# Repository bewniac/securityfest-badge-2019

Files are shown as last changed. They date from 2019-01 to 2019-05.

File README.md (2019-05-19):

# Security fest 2019 - n00Badge
Here you go, all the code and files that exist as a part of the official Security fest 2019 badge we call "n00Badge". First of all, you should know that I'm a complete n00b (hence the name) and this is my first ever project designing a PCB from scratch. I've learned a lot and it was a lot of fun with more headaches than I could count. I recommend everyone wanting to get into electronics to do what I did, get an idea what you want to do and then, like Nike say, Just do it!

The schematics and PCB design are all made in [KiCAD](http://kicad-pcb.org/) which is an Open Source Electrionics design suite. There's a lot of PCB footprints and schematic symbols for KiCAD and it's easy to make your own. There's other suites available but I use KiCAD because it was my first result on Google. 

I wanted to do something cool for Security fest 2019 and I wanted to do it myself from scratch. So I got my hands on my first ESP8266 board, the ESP-12F. It's a WiFi IoT thingy and can both work as an Access Point and a WiFi client and you can get it for 3 USD, or about 50 SEK if you buy it in Sweden. Now I have a WiFi capable microcontroller. But I wanted more. So I bought a Nokia 5110 LCD screen which costs about the same as the ESP-12F. This became my head requirements for the project:

  * Nokia 5110 LCD
  * ESP8266
  * Powered by micro USB

Simple enough. I built a prototype that could be powered by 5V micro USB. Although the components require 3.3V, but with a voltage regulator (LD1117V33) this wasn't an issue. The result was this:

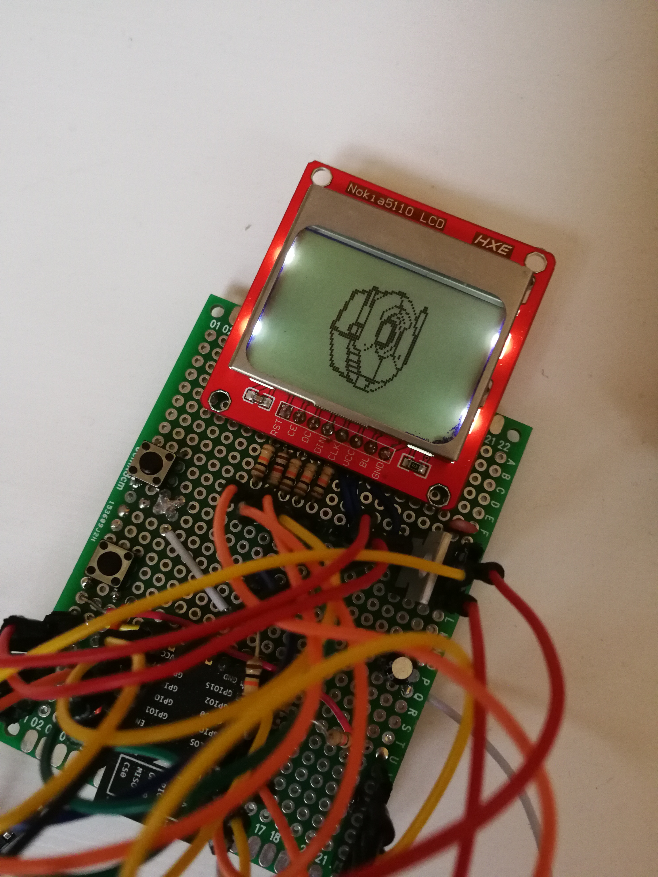
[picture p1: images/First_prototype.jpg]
First Prototype


Not so pretty, I know. But it worked. But then I wanted to create my own PCB prototype, with as much hand-solderable components as possible as I've never done SMD soldering before. I created my first schematic and PCB design in KiCAD. 

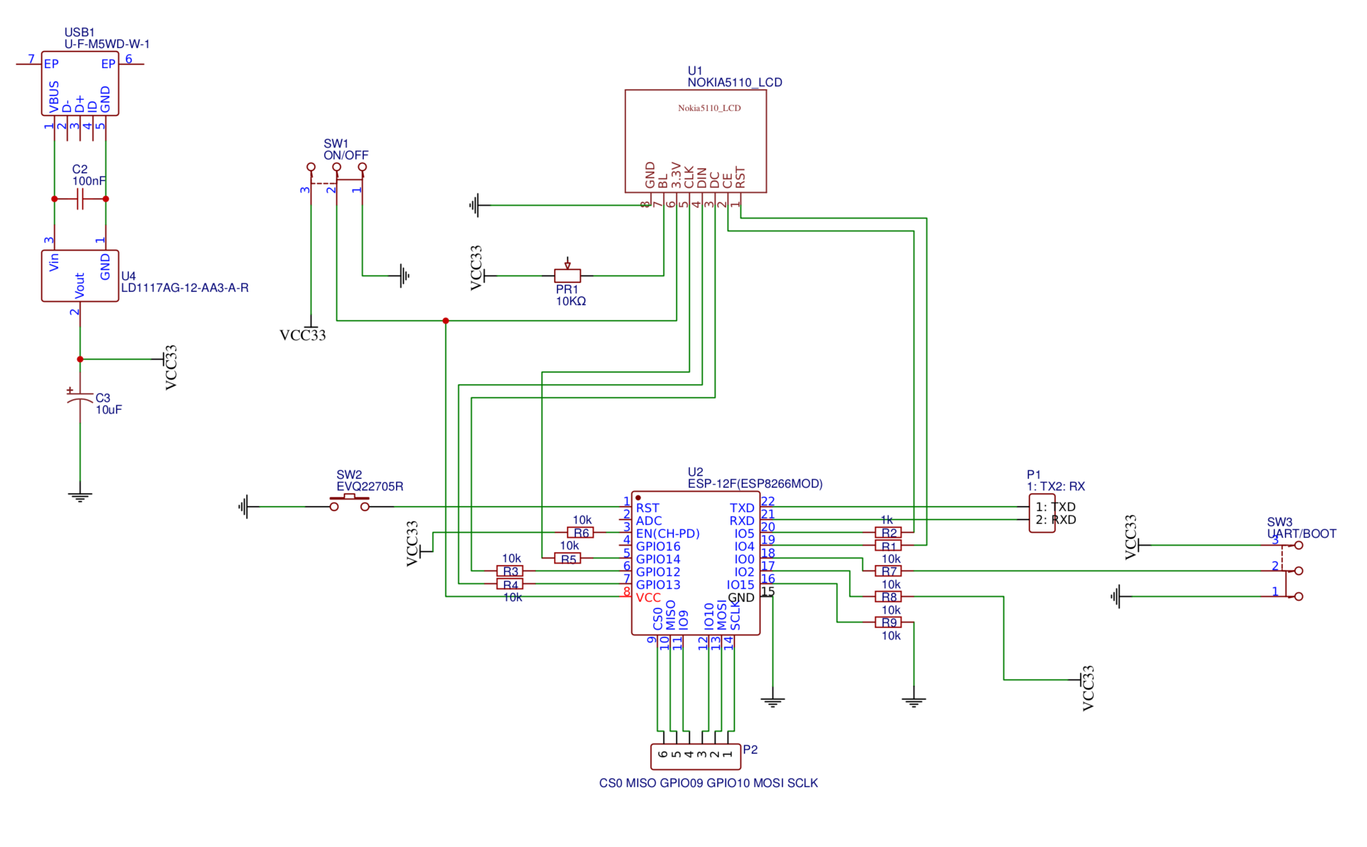
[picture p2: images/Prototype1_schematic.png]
Schematic prototype

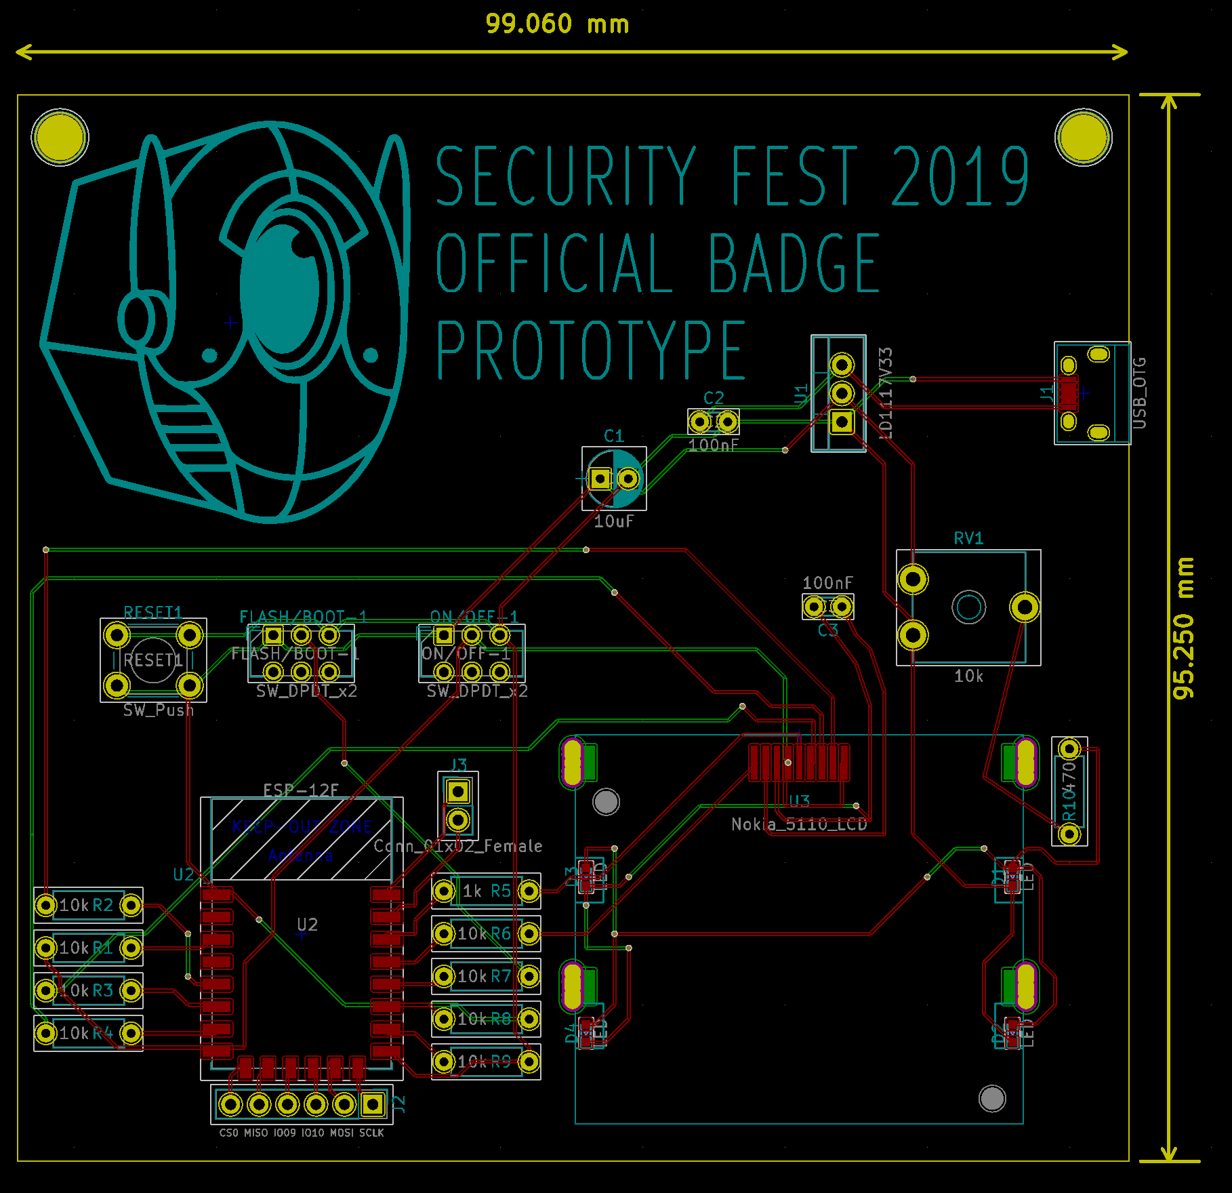
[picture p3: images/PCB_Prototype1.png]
PCB Prototype


Still not pretty, but much better than my hand-made prototype and very fun to do! I ordered 10 PCBs from https://jlcpcb.com/ and the components I was missing from https://lcsc.com/ and waited. When it arrived I was extatic! My first PCB! I soldered all the components as soon as I got it (although I had to fix some errors with the backlight LEDs at first, I forget a GND route to the backlight LEDs). 

PCB

When I did some programming trying to come up with some fun stuff to add I found I was missing something, buttons for user interaction. So I had to modify the badge a bit. I used the ADC (Analog to Digital Converter) pin to add two buttons and controll them with one pin. This can be done by adding resistors of different value to the GND leg of each button. The analog voltage is converted by the pin to a digital number. The resistors will reduce the voltage to different values on each button, hence the digital number will be differ between the buttons and I can make descisions in the code based on those values. Next I had a brilliant idea, it has to be battery powered! A Li-Po battery should do the trick. But we also like to charge the Li-Po battery. So I modified my prototype by hand, added buttons, a Li-Po battery and a Li-Po charger circuit (from Adafruit, which is open hardware and the schematics are avaiable on their website). The result was this:

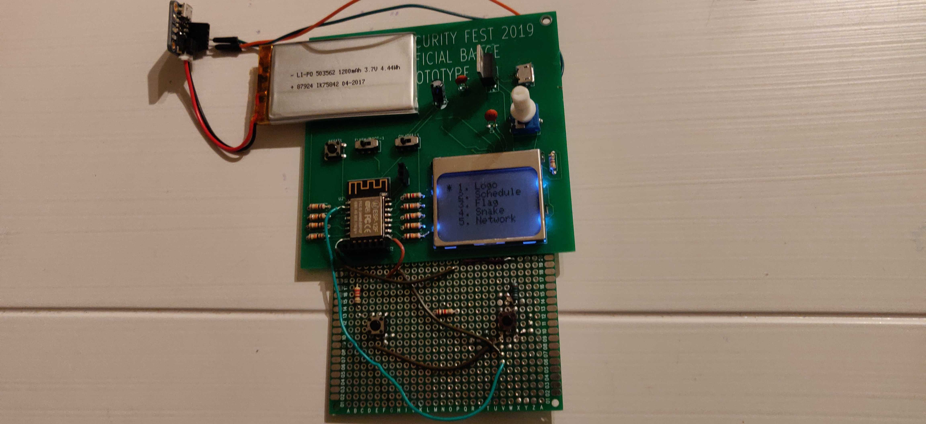
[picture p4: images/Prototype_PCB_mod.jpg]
PCB_MOD


So now I got a prototype I feel pretty good about to work on. It runs on battery and the battery can be charged, AWESOME! Now I want to make the final design. A square badge feels so boring and we've got a cool logo to work with. So I started to create a schematic including the charging curcuit (based on the Adafruit schematic) and the buttons. And I also made some changes I replaced the ESP-12F module for the new ESP-12S module. Same form-factor, removed unnecessary pins and little faster CPU frequency. I had to edit the ESP-12F module PCB footprint myself to get a footprint for the new component. 

The final schematic:

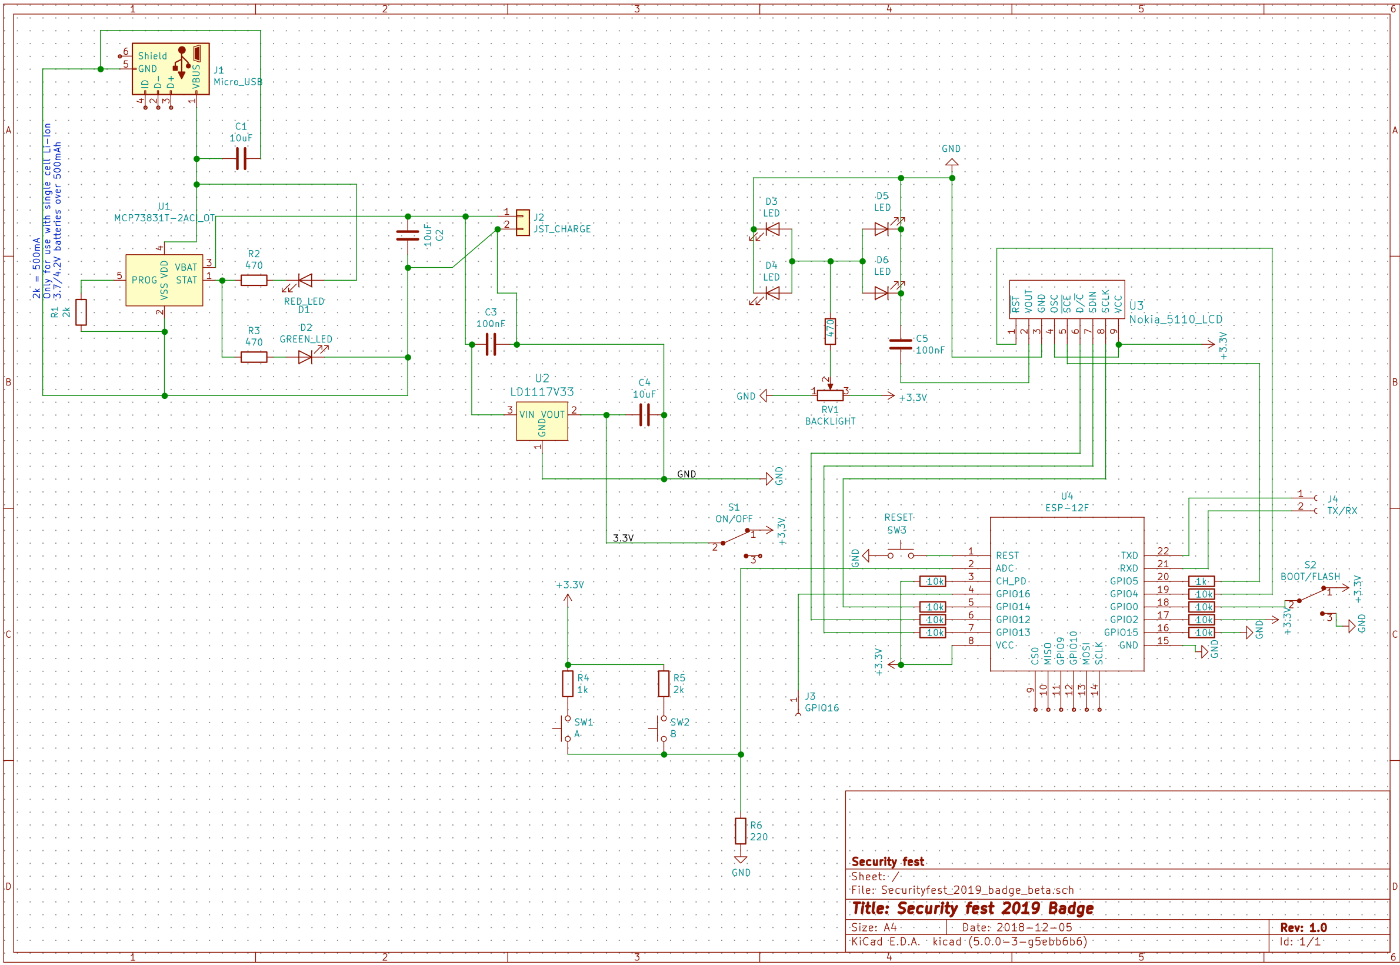
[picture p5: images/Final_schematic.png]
Final schematic


And the final PCB design:

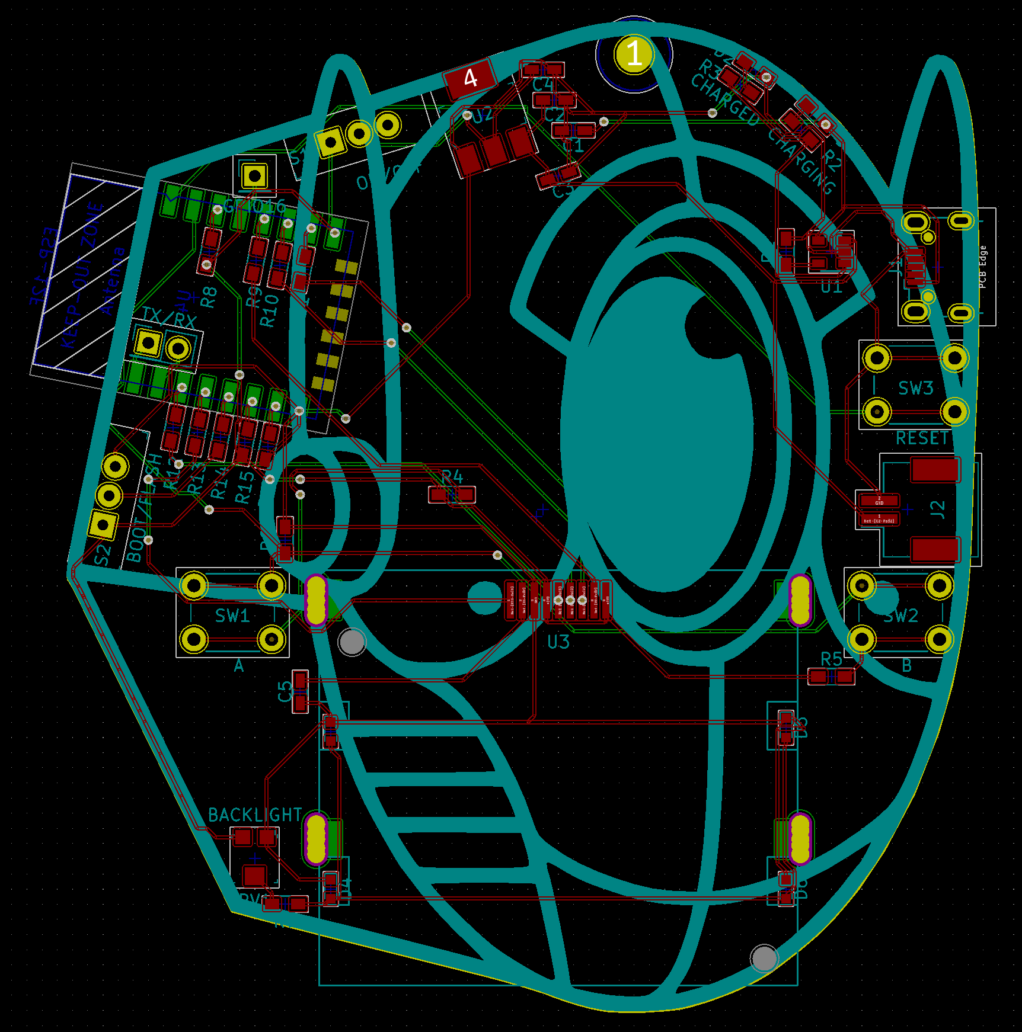
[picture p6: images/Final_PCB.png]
Final PCB


(Several month after, when we finally got the finished assembled PCB:s from seeedstudio)

F\*ck. Look at the through-holes for TX/RX. They're placed on top of the ESP-12S module. This is my fault, I'm sorry everybody. I've changed it in the PCB design now, but all your badges include that specific flaw. Also, I used a resistor connected to GPIO00 with a too much resistance. So you can't get the voltage low enough to get the system in flash mode (it stays in 1,4-1,7 V). Either bridge the connection or use a 1k resistor instead. Sorry about that. 

Schematic and PCB with fixed issues.

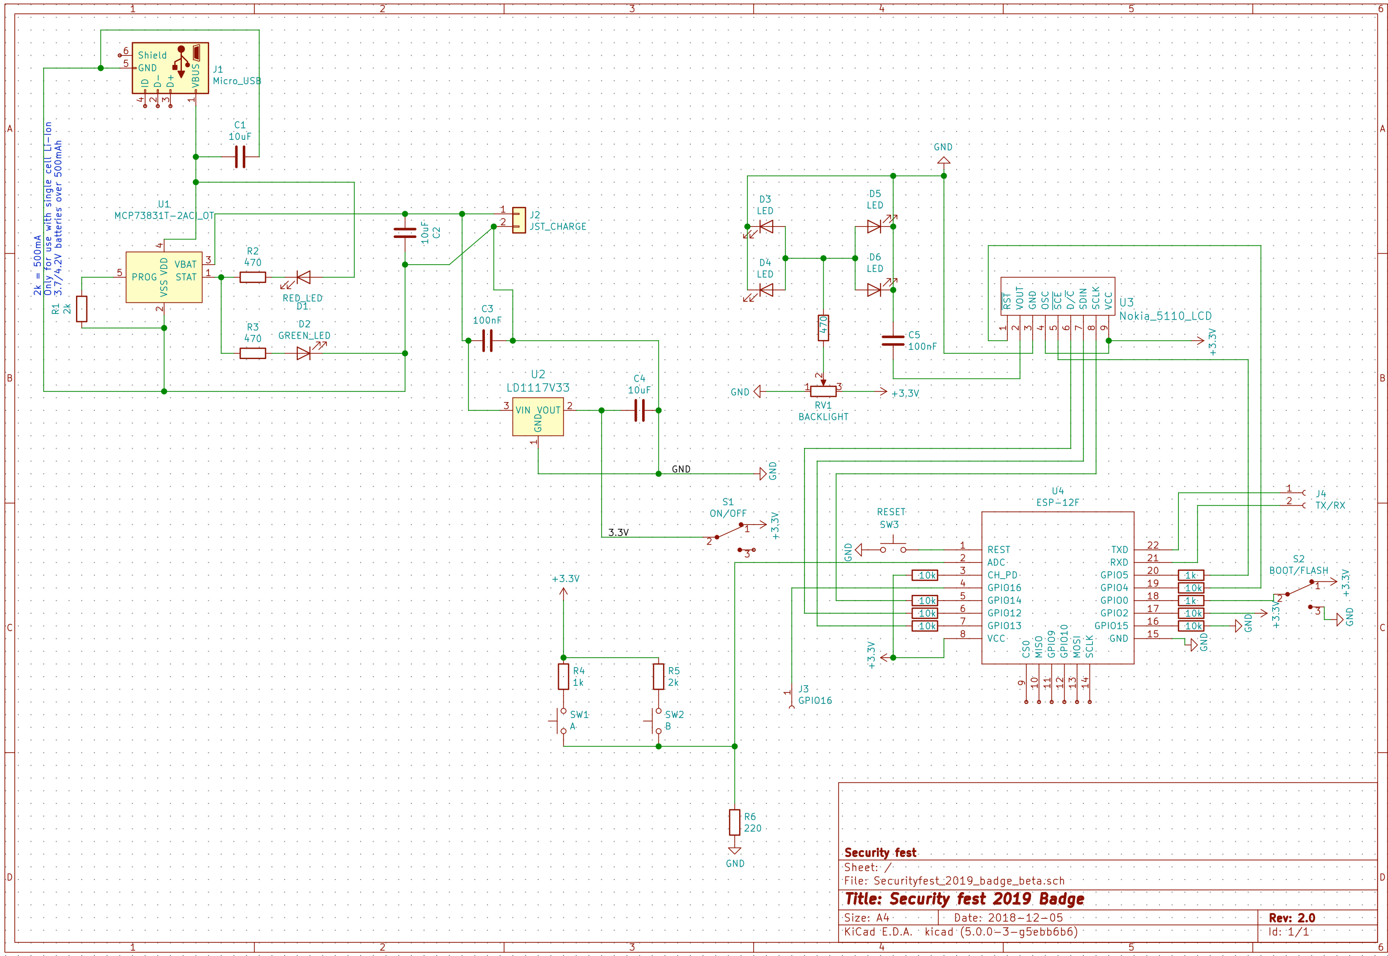
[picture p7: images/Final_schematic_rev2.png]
Final schematic


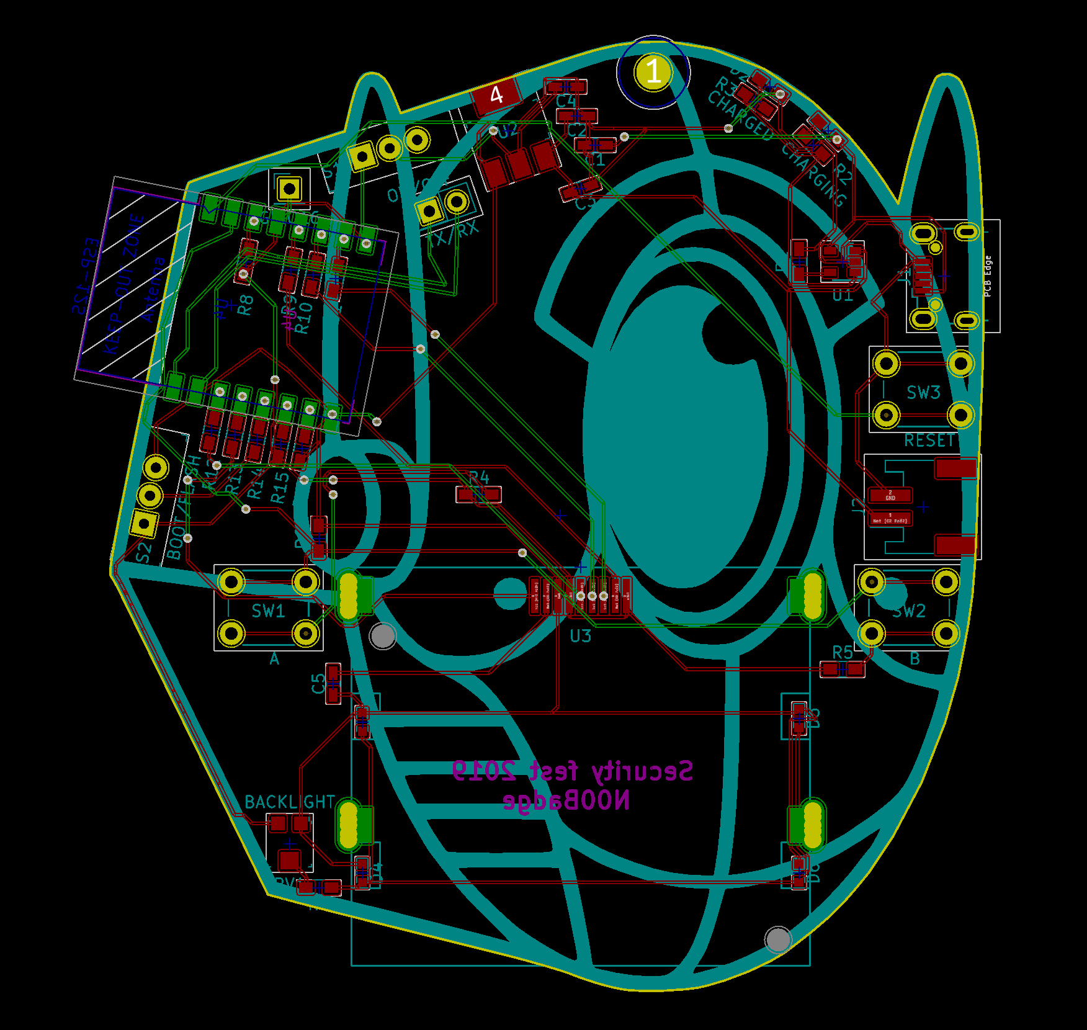
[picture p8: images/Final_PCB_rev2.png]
Final PCB


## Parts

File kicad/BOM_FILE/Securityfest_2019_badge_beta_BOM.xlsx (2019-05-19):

Designator | MPN | Qty | Link
J1 | 629105150521 | 1 | https://www.digikey.se/product-detail/sv/wurth-electronics-inc/629105150521/732-5960-1-ND/5047555
U1 | MCP73831T-2ACI/OT | 1 | https://www.digikey.se/product-detail/sv/microchip-technology/MCP73831T-2ACI-OT/MCP73831T-2ACI-OTCT-ND/1979802
R2, R3, R7 | CR0603-JW-471ELF | 3 | https://www.digikey.se/product-detail/sv/bourns-inc/CR0603-JW-471ELF/CR0603-JW-471ELFCT-ND/3740990
D1 | SML-D12U1WT86 | 1 | https://www.digikey.se/product-detail/sv/rohm-semiconductor/SML-D12U1WT86/SML-D12U1WT86CT-ND/5843858
J2 | S2B-PH-SM4-TB(LF)(SN) | 1 | https://www.digikey.ca/product-detail/en/jst-sales-america-inc/S2B-PH-SM4-TB-LF-SN/455-1749-1-ND/926846
C1, C2, C4 | CL10A106MQ8NNNC | 3 | https://www.digikey.se/product-detail/sv/samsung-electro-mechanics/CL10A106MQ8NNNC/1276-1119-1-ND/3889205
D2 | SML-D12M1WT86 | 1 | https://www.digikey.se/product-detail/sv/rohm-semiconductor/SML-D12M1WT86/SML-D12M1WT86CT-ND/5843861
U2 | LD1117S33CTR | 1 | https://www.digikey.se/product-detail/sv/stmicroelectronics/LD1117S33CTR/497-1241-1-ND/586241
C3, C5 | CL10B104KO8NNNC | 2 | https://www.digikey.se/product-detail/sv/samsung-electro-mechanics/CL10B104KO8NNNC/1276-1005-1-ND/3889091
S1, S2 | EG1218 | 2 | https://www.mouser.se/ProductDetail/E-Switch/EG1218A
U4 | esp-12s | 1 | https://item.taobao.com/item.htm?spm=a1z10.1-c.w13620763-16127750685.31.zje769&id=543467904788
SW1, SW2, SW3 | 1825910-6 | 3 | https://www.digikey.se/product-detail/sv/te-connectivity-alcoswitch-switches/1825910-6/450-1650-ND/1632536
R4, R12, R14 | CR0603-JW-102ELF | 3 | https://www.digikey.se/product-detail/sv/bourns-inc/CR0603-JW-102ELF/CR0603-JW-102ELFCT-ND/3740984
R1, R5 | CR0603-JW-202ELF | 2 | https://www.digikey.se/product-detail/sv/bourns-inc/CR0603-JW-202ELF/CR0603-JW-202ELFCT-ND/3925347
R6 | CR0603-JW-221GLF | 1 | https://www.digikey.se/product-detail/sv/bourns-inc/CR0603-JW-221GLF/CR0603-JW-221GLFCT-ND/3925351
R8, R9, R10, R11, R13, R15, R16 | RMCF0603JT10K0 | 8 | https://www.digikey.se/product-detail/sv/stackpole-electronics-inc/RMCF0603JT10K0/RMCF0603JT10K0CT-ND/1943191
D3, D4, D5, D6 | IN-S63AT5UW | 4 | https://www.digikey.se/product-detail/sv/inolux/IN-S63AT5UW/1830-1063-1-ND/7604706
RV1 | TC33X-2-103G | 1 | https://www.digikey.se/product-detail/sv/bourns-inc/TC33X-2-103E/TC33X-103ECT-ND/612911

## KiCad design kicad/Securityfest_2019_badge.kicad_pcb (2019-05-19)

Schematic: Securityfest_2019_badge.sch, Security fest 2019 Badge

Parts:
C1, C2, C4: 10uF; C_0603_HandSoldering
C3, C5: 100nF; C_0603_HandSoldering
D1: RED_LED; LED_0603_HandSoldering
D2: GREEN_LED; LED_0603_HandSoldering
D3, D4, D5, D6: LED; LED_0603
J1: Micro_USB; USB_Micro-B_Wuerth-629105150521
J2: JST_CHARGE; JST_PH_S2B-PH-SM4-TB_02x2.00mm_Angled
J3: GPIO16; Pin_Header_Straight_1x01_Pitch1.00mm
J4: TX/RX; Pin_Header_Straight_1x02_Pitch1.00mm
R1, R5: 2k; R_0603_HandSoldering
R2, R3, R7: 470; R_0603_HandSoldering
R4, R12, R14: 1k; R_0603_HandSoldering
R6: 220; R_0603_HandSoldering
R8, R9, R10, R11, R13, R15, R16: 10k; R_0603_HandSoldering
RV1: BACKLIGHT; Trimpot_3.8mmx3.6mm_TC33X-2-103E
S1: ON/OFF; Switch_Slide_11.6x4mm_EG1218; MPN EG1218; Digi-Key_PN EG1903-ND
S2: BOOT/FLASH; Switch_Slide_11.6x4mm_EG1218; MPN EG1218; Digi-Key_PN EG1903-ND
SW1: A; SW_PUSH_6mm_h5mm
SW2: B; SW_PUSH_6mm_h5mm
SW3: RESET; SW_PUSH_6mm_h5mm
U1: MCP73831T-2ACI_OT; SOT-23-5
U2: LD1117V33; SOT-223; MPN LD1117V33; Digi-Key_PN 497-1491-5-ND
U3: Nokia_5110_LCD; Nokia_5110-3310_LCD
U4: ESP-12F; ESP-12E

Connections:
+3V3: R4.1, R5.1, R8.2, R15.1, RV1.3, S1.1, S2.1, U3.4, U3.9, U4.8 (VCC)
/3.3V: C4.2, S1.2, U2.2
GND: C1.1, C2.1, C3.1, C4.1, C5.1, D2.1, D3.1, D4.1, D5.1, D6.1, J1.5, J2.2, R1.2, R6.2, R16.1, RV1.1, S2.3, SW3.1, U1.2, U2.1, U3.3, U4.15 (GND)
unnamed: C1.2, D1.2, J1.1, U1.4
unnamed: C2.2, C3.2, J2.1, U1.3, U2.3
unnamed: C5.2, U3.2
unnamed: D1.1, R2.1
unnamed: D2.2, R3.1
unnamed: D3.2, D4.2, D5.2, D6.2, R7.1
unnamed 12: U4.4 (GPIO16); also elsewhere on the board
unnamed 13: U4.22 (TXD); also elsewhere on the board
unnamed 14: U4.21 (RXD); also elsewhere on the board
unnamed: R1.1, U1.5
unnamed: R2.2, R3.2, U1.1
unnamed: R4.2, SW1.2
unnamed: R5.2, SW2.2
unnamed: R6.1, SW1.1, SW2.1, U4.2 (ADC)
unnamed: R7.2, RV1.2
unnamed: R8.1, U4.3 (CH_PD)
unnamed: R9.1, U4.5 (GPIO14)
unnamed: R9.2, U3.8
unnamed: R10.1, U4.6 (GPIO12)
unnamed: R10.2, U3.6
unnamed: R11.1, U4.7 (GPIO13)
unnamed: R11.2, U3.7
unnamed: R12.1, U3.5
unnamed: R12.2, U4.20 (GPIO5)
unnamed: R13.1, U3.1
unnamed: R13.2, U4.19 (GPIO4)
unnamed: R14.1, S2.2
unnamed: R14.2, U4.18 (GPIO0)
unnamed: R15.2, U4.17 (GPIO2)
unnamed: R16.2, U4.16 (GPIO15)
unnamed: SW3.2, U4.1 (REST)

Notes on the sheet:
2k = 500mA Only for use with single cell Li-Ion 3.7/4.2V batteries over 500mAh

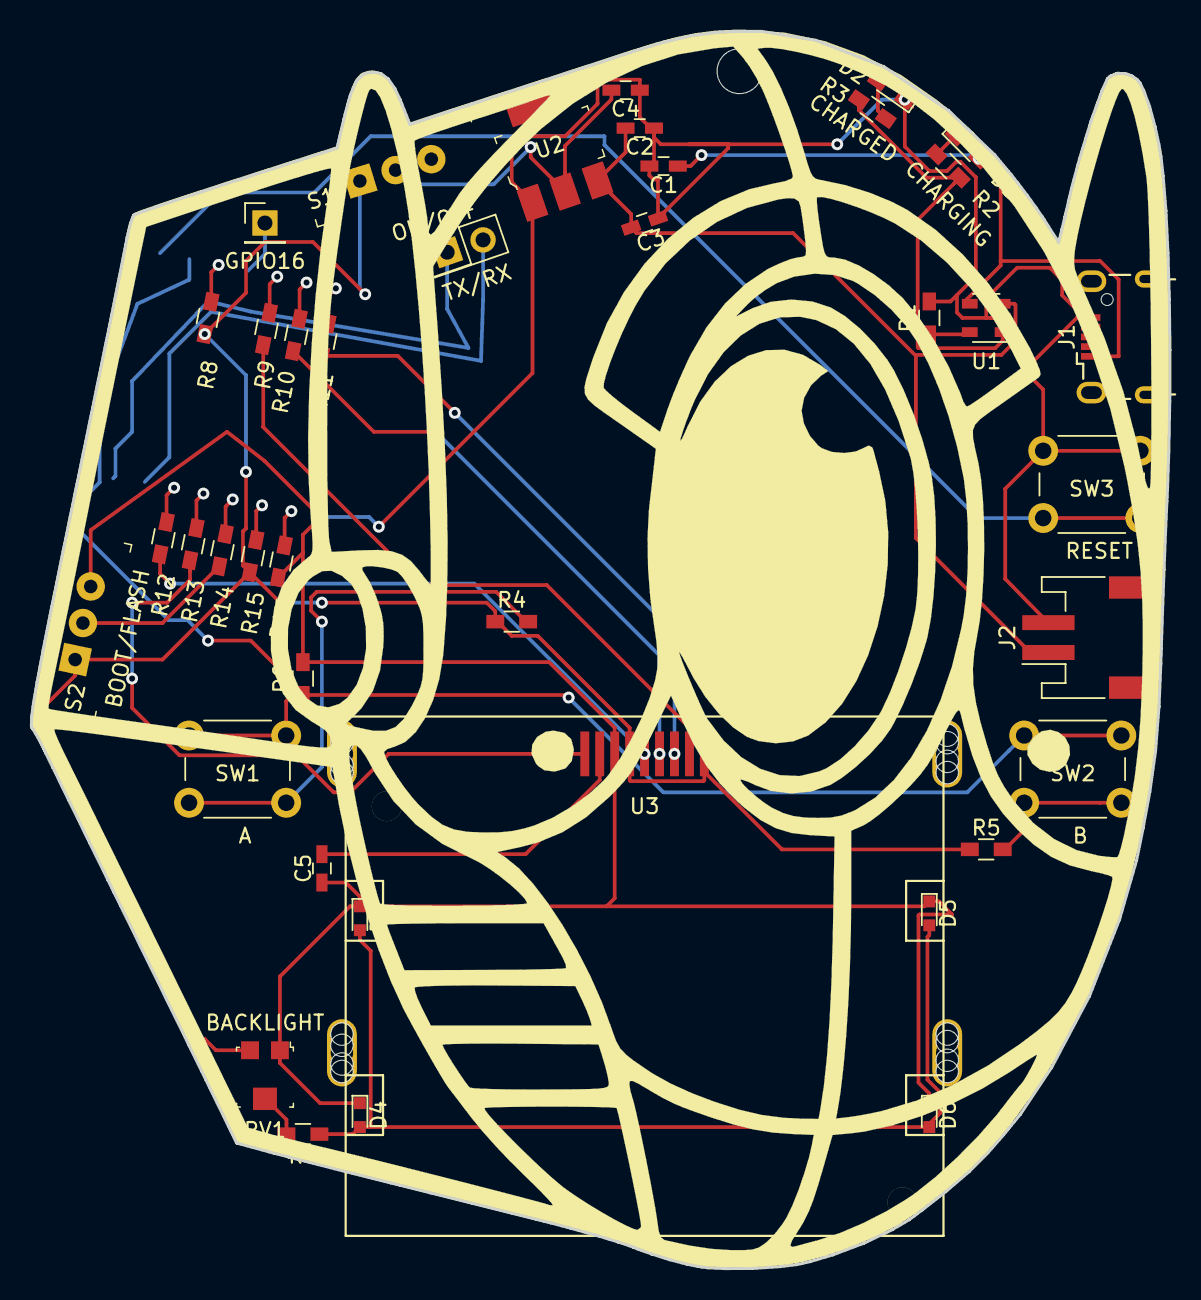
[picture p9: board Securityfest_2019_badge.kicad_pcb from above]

Board: 2 copper layers, 76.2 x 82.8 mm, 41 parts (1 on the bottom side), 34 nets.

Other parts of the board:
GPIO16: GPIO16; Pin_Header_Straight_1x01_Pitch2.54mm
TX/RX: RX/TX; Pin_Header_Straight_2x01_Pitch2.54mm

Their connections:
unnamed 12: GPIO16.1; also elsewhere on the board
unnamed 13: TX/RX.1; also elsewhere on the board
unnamed 14: TX/RX.2; also elsewhere on the board

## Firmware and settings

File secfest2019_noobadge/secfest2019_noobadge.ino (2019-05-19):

 // https://arduino-esp8266.readthedocs.io/en/
#include <ESP8266WiFi.h>
#include <ArduinoOTA.h> 
#include <FS.h>
// https://github.com/bbx10/Adafruit-PCD8544-Nokia-5110-LCD-library/tree/esp8266
#include <Adafruit_GFX.h>
#include <Adafruit_PCD8544.h>
// https://gitlab.com/painlessMesh/painlessMesh
#include <painlessMesh.h>
#include "bitmaps.h"
#include "snake.h"

#define   MESH_PREFIX     "SECFEST_19"
#define   MESH_PASSWORD   "SECFEST_19_PSK"
#define   MESH_PORT       5555

#define BUTTON_ADC 400
#define LCD_MAX_CHARS 84

// Mesh
painlessMesh  mesh;
void receivedCallback(uint32_t from, String & msg);
void newConnectionCallback(uint32_t nodeId);

/*
   GPIO14 - Serial clock out (SCLK)
   GPIO13 - Serial data out (DIN)
   GPIO12 - Data/Command select (D/C)
   GPIO05 - LCD chip select (CS)
   GPIO04 - LCD reset (RST)
*/
Adafruit_PCD8544 display = Adafruit_PCD8544(14, 13, 12, 5, 4);

// Variables

// Variables used for timing. Delay() sucks and break shit.
long lastTimeButton = 0;
long buttonDelay = 150;
long secretDelay = 10000;
long lastTimeSecret = 0;
bool scrolling = false;
long lastTimeScrolling = 0;
long scrollingDelay = 150;
int scrollPos = 0;
bool printingLongText = false;
String textLeft = "";
String macAddr = WiFi.softAPmacAddress().c_str();
int maxRows = 6;
String menu_items[5] = {"Logo", "Schedule", "Snake", "Network", "Secret"};
String net_menu[3] = {"Network", "Scan", "Exit"};
String *CurrentMenu = menu_items;
String *networks_menu;
int CurrentMenuSize = (sizeof(menu_items) / sizeof(String));
int CurrentItem = 0;
int bPressed = 0;
String schedule[26] = {
  "-- MAY 23 --", 
  "08:30 Registration and breakfast", 
  "09:00 Hello and welcome", 
  "09:20 Shira Shamban - Your internet is down? It’s cyber warfare, stupid", 
  "10:20 Christoffer Jerkeby - Load Balancer with RCE, Hacking F5", 
  "11:20 Olle Segerdahl - DOMXSS is not Dead", 
  "12:30 Lunch", 
  "13:30 Hugo Hirsh - Trust and Sugar", 
  "14:30 Csaba Fitzl - macOS - Gaining root with Harmless AppStore Apps", 
  "15:20 Coffee break", 
  "15:45 Alex Inführ - Exploring Macros in (Open|Libre)office - Why you should care", 
  "16:45 Samit Anwer - Oh! Auth: Implementation pitfalls of OAuth 2.0 & the Auth Providers who have fell in it", 
  "17:45 Calle Svensson - Software Obfuscation with LLVM", 
  "19:45 Dinner, drinks and awards", 
  "21:45 After party!", 
  "-- MAY 24 --", 
  "08:30 Breakfast", 
  "09:00 Dave Lewis - Zero Trust & The Flaming Sword of Justice!", 
  "10:15 David Fiser - Falling Out of the Sky: Security Risks that can Bring Your Cloud Down to the Ground", 
  "11:30 Dennis Kolegov - A dive in to SD-WAN Insecure Designs and Vulnerabilities", 
  "12:30 Lunch", 
  "13:30 Hanno Böck - Don't Sniff the MIME", 
  "14:45 Himanshu Mehta - RF Exploitation: Demystifying IoT/OT hacks with SDR", 
  "15:45 Mazin Ahmed - Practical Approaches for Testing and Breaking JWT Authentication", 
  "16:45 Goodbye <3", 
  "Exit."};
  
String secret = "UNSET";
uint32_t masterNode = 3157003985;

// Used to catch messages on the mesh network.
void receivedCallback( uint32_t from, String &msg ) {
  String recv = msg;
  if (recv.startsWith("secret:")) {
    secret = recv;
    printLongText(secret);
  } else {
    printLongText(msg);
  }
}

int ADC_Button = A0; // ADC - Analog digital converter pin for buttons

void setup(void) {
  pinMode(ADC_Button, INPUT);

  // Serial for debugging
  Serial.begin(115200);
  Serial.println();
  Serial.println("N00badge v0.1");
  mesh.init(MESH_PREFIX, MESH_PASSWORD, MESH_PORT);
  mesh.setDebugMsgTypes( ERROR | COMMUNICATION );
  mesh.onReceive(&receivedCallback);
  mesh.setContainsRoot();

  // Display setup
  display.begin(60);
  display.setTextSize(0);
  
  PrintMenu(CurrentMenu);
}

void loop(void) {
  // Mesh update
  mesh.update();

  long timeSecret = millis();
  if ((timeSecret - lastTimeSecret) >= secretDelay) {
    lastTimeSecret = timeSecret;
    if (secret == "UNSET") {
      String msg = "giveme";
      mesh.sendSingle(masterNode, msg);
    }
  }

  long timeButton = millis();
  if ((timeButton - lastTimeButton) >= buttonDelay) {
    lastTimeButton = timeButton;
    bPressed = analogRead(ADC_Button);
    buttonPress(bPressed);
  }

  // Scrolling text
  long timeScrolling = millis();
  if ((timeScrolling - lastTimeScrolling) >= scrollingDelay) {
    if (scrolling) {
      display.setCursor(0, (8 * (CurrentItem % 6)));
      display.setTextColor(WHITE, BLACK);
      for (int i = 0; i < 14; i++) {
        display.print(CurrentMenu[CurrentItem][scrollPos + i]);
      }
      scrollPos++;
      lastTimeScrolling = timeScrolling;
      if (CurrentMenu[CurrentItem].length() == scrollPos) {
        scrolling = false;
        scrollPos = 0;
      }
      display.display();
    }
  }

}
void buttonPress(int button) {
  if (100 < button) { // A button is pressed
    // If button is pressed then we should restore scrollPos and stop scrolling.
    scrollPos = 0;
    scrolling = false;
    if ( button < BUTTON_ADC ) {  // Action button
      if (printingLongText) {
        printLongText(textLeft);
      } else {
        Action(CurrentMenu);
      }
    }
    if (BUTTON_ADC < button) { // Move button
      CurrentItem = ((CurrentItem + 1) % CurrentMenuSize);
      PrintMenu(CurrentMenu);
    }
  }
}

void printLongText(String text) {
  printingLongText = true;
  display.setTextColor(BLACK, WHITE);
  display.clearDisplay();
  if (text.length() > LCD_MAX_CHARS) {
    textLeft = text.substring(84, text.length());
    String line = text.substring(0, LCD_MAX_CHARS);
    line.trim();
    display.print(line);

  } else {
    for (int i = 0; i < text.length(); i++) {
      display.print(text[i]);
    }
    printingLongText = false;
  }
  display.display();
}

void PrintMenu(String *menu) {
  display.clearDisplay();
  int firstItem = CurrentItem - (CurrentItem % 6);
  for (int i = firstItem; i < CurrentMenuSize; i++) {
    if (CurrentItem == i) {
      display.setTextColor(WHITE, BLACK);
    } else {
      display.setTextColor(BLACK, WHITE);
    }
    if (menu[i].length() < 14) {
      display.println(menu[i]);
    }
    else {
      for (int c = 0; c < 14; c++) {
        display.print(menu[i][c]);
      }
    }
  }
  if (CurrentMenu == menu_items) {
    display.drawBitmap(40, 0, logo, 48, 48, 1);
  }
  display.display();
  if (13 < menu[CurrentItem].length()) {
    scrolling = true;
  }
  display.display();
  display.setTextColor(BLACK, WHITE);
}

void Action(String *menu) {
  if (CurrentMenu == menu_items) {
    switch (CurrentItem) {
      case 0:
        printLogo();
        break;
      case 1:
        CurrentItem = 0;
        CurrentMenu = schedule;
        CurrentMenuSize = (sizeof(schedule) / sizeof(String));
        PrintMenu(CurrentMenu);
        break;
      case 2:
        snake();
        break;
      case 3:
        CurrentItem = 0;
        CurrentMenu = net_menu;
        CurrentMenuSize = (sizeof(net_menu) / sizeof(String));
        PrintMenu(CurrentMenu);
        break;
      case 4:
        printLongText(secret);
        break;
      default:
        PrintMenu(CurrentMenu);
    }
  } else if (CurrentMenu == net_menu) {
    boolean result;
    switch (CurrentItem) {
      case 0:
        printNetwork();
        break;
      case 1:
        display.clearDisplay();
        display.println("Wait for it...");
        display.display();
        ScanNetwork();
        /* When scanning is complete create a access point once more */
        WiFi.mode(WIFI_AP);
        result = WiFi.softAP(MESH_PREFIX, MESH_PASSWORD);
        if (result) {
          Serial.println("Success setting up AP");
        }
        else {
          Serial.println("Failed setting up AP");
        }
        CurrentItem = 0;
        CurrentMenuSize = sizeof(networks_menu);
        CurrentMenu = networks_menu;
        PrintMenu(CurrentMenu);
        break;
      case 2:
        CurrentItem = 0;
        CurrentMenuSize = (sizeof(menu_items) / sizeof(String));
        CurrentMenu = menu_items;
        PrintMenu(CurrentMenu);
        break;
      default:
        PrintMenu(CurrentMenu);
    }
  } else if (CurrentMenu == networks_menu) {
    switch (CurrentItem) {
      case 3:
        CurrentItem = 0;
        CurrentMenuSize = (sizeof(net_menu) / sizeof(String));
        CurrentMenu = net_menu;
        PrintMenu(CurrentMenu);
        break;
      default:
        PrintMenu(CurrentMenu);
    }
  } else if (CurrentMenu == schedule) {
    switch (CurrentItem) {
      case 25: // EXIT
        CurrentItem = 0;
        CurrentMenuSize = (sizeof(menu_items) / sizeof(String));
        CurrentMenu = menu_items;
        PrintMenu(CurrentMenu);
        break;
      default:
        PrintMenu(CurrentMenu);
    }
  }
}

void ScanNetwork() {
  WiFi.mode(WIFI_STA);
  WiFi.disconnect();
  int numberOfNetworks = WiFi.scanNetworks();
  String encType = "";
  display.clearDisplay();
  display.display();
  networks_menu = new String[numberOfNetworks + 1];
  for (int i = 0; i < numberOfNetworks; i++)
  {
    int et = WiFi.encryptionType(i);
    if (et ==  ENC_TYPE_WEP) {
      encType = "WEP";
    } else if (et == ENC_TYPE_TKIP) {
      encType = "WPA";
    } else if (et == ENC_TYPE_CCMP) {
      encType = "WPA2";
    } else if (et == ENC_TYPE_NONE) {
      encType = "Open";
    }
    networks_menu[i] = String(i + 1) + ": " + WiFi.SSID(i).c_str() + " Ch:" + WiFi.channel(i) + "(" + WiFi.RSSI(i) + "dBm) " + encType;
  }
  networks_menu[numberOfNetworks] = "Exit";
}
void printNetwork(void) {
  display.clearDisplay();
  display.println(MESH_PREFIX);
  display.println(MESH_PASSWORD);
  display.println(IPAddress_toString(WiFi.softAPIP()));
  display.display();
}
String IPAddress_toString(IPAddress ip) {
  String IpAddress = "";
  for (int i = 0; i < 4; i++) {
    IpAddress += String(ip[i]);
    if (i < 3) {
      IpAddress += ".";
    }
  }
  return IpAddress;
}
void snake(void) {
  Game g(ADC_Button);
  g.Run(display);
}

void printLogo(void) {
  display.clearDisplay();
  display.drawBitmap(18, 0, logo, 48, 48, 1);
  display.display();
}

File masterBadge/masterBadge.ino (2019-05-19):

// https://github.com/bbx10/Adafruit-PCD8544-Nokia-5110-LCD-library/tree/esp8266
#include <FS.h>
#include <Adafruit_GFX.h>
#include <Adafruit_PCD8544.h>
// https://gitlab.com/painlessMesh/painlessMesh
#include <painlessMesh.h>

#define   MESH_PREFIX     "SECFEST_19"
#define   MESH_PASSWORD   "SECFEST_19_PSK"
#define   MESH_PORT       5555

// Mesh
painlessMesh  mesh;
void receivedCallback(uint32_t from, String & msg);
void newConnectionCallback(uint32_t nodeId);
char* secrets[200] = {"1-50f50b00fe89109c41a47ced21dfead2a763dfa83d39a9dec1975b00c76a9a74055dd7", "2-ab3a5576a7af87eb35f4311601c7676474686e246e0481bea7c0bb88e3dada48aee836", "3-6415f67f8ea4c42a886cc3f9fe0dbe6cdc8fe831f7c182275a617c6a2d994acad25a94", "4-5ce5bf43bf34b6e6a4489b07e0ae001a50d0d845d4c44e9d890c708a051d6d636e656b", "1-2e80181242289da250c2fed27a37cb6f8b7c08fc250b7c6fb28225c4875a7fac3e42cc", "2-5a007c417569032e015b0c71ee6368c8a33249134a01b40ca9ea2f5e05efe31e6184bb", "3-eb5acc5ae0c3cdd1ada57ca14a41907d27ca1852cbf66224275e96788b9c9644262902", "4-89d1d166b4afc588949e05ad5e372c19c3f2b057cd4c5eba3558fc5e5024d45415f4b8", "1-e31c71128fbe9303abc8dc9ab0cc276ddffb41442ab98b443df78d482e515ed3daf260", "2-0985cef9e16800a26458eaf4b58278a020e59015d04c42bd59f5aa0ae1a160469711d1", "3-754317e2b954c0fc33acb86cdb5b6c17f09a88ec5e0963be5834bba0c6d93463340cc4", "4-0c2f36f3a019b9ae12c740f4d1ae2d786f382b80ed77d0426eb4a7c141dad47907005f", "1-b978bd7a768f79f167dd87b2cf0e925327893c83b871195aade3bdc45aee2f55cf0c9e", "2-5407be08c16b0584fc91c030abeb4c1f19bc36224ae7c1f46a09df5bd8b1833ae8d603", "3-72a5ab7b60662f286770c980baf0ed9631b1531c566a72e9fbdcfe7d8b76a6995e35e8", "4-12047792a99cf0ef20db672f6acd3f0d3b7e110d24ca4b00461c1c4472431340a8612c", "1-1b108af0829f9095384ba253e3169a8689ee883f4d202f9bc213c83f55db082f51817d", "2-70c73aa4922becd3ae01499d4fc4982a1183882a14c966768e356b3302d4fa2f27bbf1", "3-f40d185dc7362f1b6a7665cc72c7317697e959a8fd15e3aa70103fee5e26f8f60fd5f9", "4-dbc6d02ce299cc3e33097dca52ed811e78c230db4aa42c0561140aeed6b53ee8ff68a9", "1-0c6d2544255ff85ac9e961fb43c41edd2f7a86ab511c6a202b510f5911b352f4580223", "2-2af2f9465604e8fb8e7bc403f0b58189b1e40ac7398f4be00e65bab20781b51f77258e", "3-b945740ba4d943fcbbae2bfa6d64ac8e911ad5d1cc6f8b87190229091f1bed1d56c8d8", "4-bc9725c7447892b17f004dc8d75ff60a8d334a1544d2ecad2ae0d4daea084a9150357e", "1-4bbfd2425d179d27c65e94560169347b1ca7c60e6f9c7d5ba15d023c9c9e6e24ee9e96", "2-efb73a211eda3c7e347daecb973f381dfc65483a0be3807e6b97d9af2fe3a08a873faa", "3-3bd2406a944ff2040e1fb49f48433fbcef46d789c0835762f6fc4771ba54c458104e49", "4-1d9c16a734fd42449eaa9e1393093642bedec1321db8ee3426adf5b8722dd168c48c0e", "1-b3f60739d963fbf506f51edd2a7b1296e243e4bdd57ae259aaa64569fd8d79adf85f75", "2-decd794528899aa65633ec94da939400681397af2f58688b624531779d6fa5961f9354", "3-f2e1d6752668320eacfa7c4b2efdb54c85d42aaf5ede2095f4d5e8fc69cbd6cd9e2354", "4-78cf3623a2b7a203d65347896673e96030c915d11114641a4d99bdc0d59d736b2167e9", "1-08f7d2257339576d34545fe835384341c13b95d05ad5664d45a12eff3b0681e957b2ae", "2-85f71fc6e114aeafbef9ca1cdeb50f68964e2f8aa719b3b46c783046a355631d419d38", "3-12da65ea45afaa9f76911bf635987ff358f1e3e759307fbe15ef825b917ae8026fc0e3", "4-7a5cc9ce452c7ef631e5991184be3cab2ec70e605dec9e3f112ce7d0655c26759a24cd", "1-cc1eb33855ae8e9a4551267d1303dcf1ad1b38f477235d94b79b94e0745c4050c89460", "2-b169e4d0eb21a0c8ed3c61ece46831fefb968822626bbbebe64d0acf3c7eecd9823405", "3-e2adffe1690d7d0f5451c993297eded55909e96bb1b44c386de002cd410ba67f334f10", "4-e651db534d2c941e5153ad982bac465d2311b6b3ad717131bc47a81f5d730b23eae8ed", "1-384f1ca13a717fd6b60e6b5b3a37062fb798db5ebfda3a501731c3885780cff1c9d31c", "2-7ade2328cd0c3dcdb272b4c7118596f313e39b1bb9ac8b5d121927da2c7d1382751148", "3-dd4b978020ff1146f840519ef5a7a306abff19f8a28a1b4a391e78b072d4d685c52d21", "4-fd6c3788e73e5066080f3a515e6742818630c1713228eca280edfd20239f75f3d20612", "1-77500ae44c9efce12c580b9f71561432d13d914e11b8fcb929d85248c2d3e08db6d2ae", "2-1467dacc213b8d034f051dd72a994ebd37fb17fb8bfb9359efef57b52b4f6057eb8f27", "3-fced7821ba2722bf9f61984a85da6955e942df083ebfc5a7fa01991fe0b58a2c24b2fc", "4-e20091f938f3eb7cd58dca139f2503ce6b49bbb4eccc8bf17b9452469bab26ed6d488f", "1-2bf2348f4a70e3d2f1b07bc07e23d35ee40d2174c3e7cf8db9379df3dbe16931e77157", "2-50ba01ece62a281526446055a4b496dff25f24cbd298633cb6045f5ad4cc419eba3d03", "3-e4929d6a7bd8989a2bc895970482765b19d65c02b58306f633055e4b0604225924a321", "4-9dddb8639de6cc974d4945e4c067e9e15f1490c3a97d330a28901dfe5335afb805fdf0", "1-377d55047cae80fb43ffe9d4ee59dde7ea706116b96d62486b64cb3317ab28816cc981", "2-2a24440ff1bc992efd0d3748a0ac82f91733e1e7ff6e997bc7060a5ddc70bd569d5198", "3-8283b9025a904a8842ce509e90e06cc4f2c7d94ce2ff517490545d8cc2f29f2188776c", "4-66e328705a6273420482270e5be7e4ff73940d38911e40b79c0755ea02eda88c8b523f", "1-5eb33e6f1e2d3ead48ed53e3d153115437bc3a1168a27e004a12d00620860656eb61ba", "2-f7652143d5b8a9d40f6a1e44455e8bd019ca71b9d49a0ec3cea1f2f07c4de7147c4d7f", "3-360cb7251c17c424bbbbc3a54a18a95e21f2121518c4da84b885be1455e2ebb4eec3b0", "4-e7172c83966723ec7145009dff9db797bbe3b4c2e75dd366a2679fae7b0b03bef05b90", "1-d1e7c2386ce89515e91e5e1d95dd64280e4d0dbf45cc7dc907cfe531db672f1d08dc7f", "2-dc4a3993320b423c4a0bdaa422f0396d16fead9f26986ed621b180da0e90e66dbdb3af", "3-927753a2896184745f290abb69386e9f1737f99dc7a8b9581a48f909dcdec386cc80a5", "4-67529cda51e20658e199f52e8a09b3f856d0c165a0208d50aeef1aec8acc4ef569bbcc", "1-7ef196f865f7a65a4dade7468d37ffb65c01180ccc8bc4bae620938d515bb2e1524433", "2-55cdfa5b7da115e967aff99b876c3cf11547ea3c79ced1181323f2ae5bd76f67b627b4", "3-b4e6c4aacfd4e0eed63e90dfd44ef09d46c2ab8d11b9bfe5c935fdc103a5d7709d8cf2", "4-2af0b26bb8e66cdb29dcf57790157242cd27fd3229eac66b0ef9823124b9972b840d28", "1-e08354803328f2e2238ce296c7395f05d99d21f409b1e225b2f54ec228c65933b254ca", "2-e6d51d1eae859a5f733e1af717c0149c369a0392c2272d8196e3a067d3dbe2ffbe6bcc", "3-998ce1974a2f3be0ac8e76630eec7843e0837bdb6f6a65e318207247f234b13a75d073", "4-7334f235e4c7e8ac23b0909ea38886b0290a4713984ff9c4b4d686ffd87de4ecb52d0b", "1-26f707f908ad19979ded8ff6ebb40546f6a0bbcd21cc7cd3e802aa014ea6e34bd448b7", "2-288b3a24799fe0880dfc6d6da0b596c05de1af864f823dcf90531b1603955c89ca822d", "3-91a695d4a6b0aa426c2d6c999514a05ca4c54df6cab2eb5b44672df5441ab5346725ef", "4-e552bb62cab5adf2d636cac074df59602bff7ea1f67d6fd274ca3bc00adfb21abfb231", "1-317c5ca9a92b97daed18f473813b74881250b7791b394f8b4777c08013689909337283", "2-315ecfd08db67bf9686e309651b22da68b50370c914cc79eda6f8a2882baee18a37f4d", "3-9ff83b70f31fbf7e794a4ae70e9c6af49684d9c82e892252a12ed64a98fb7de7e9e2bb", "4-0df45dddfe7484be0cf0daf306b54c41fbda483ee772e8f0b3ea094de24dcf6af26cd1", "1-668b571b82f6413269ba8367fd1fbb3b4dba657f01101d28bc05991966d708b5948dc7", "2-858757a6ccf25a3545357f0caa4716dac38942f7366427bb1786b361908458ed0f3aec", "3-7cd6a8b49986485ad0b37269894d9e3b81b77e35938890d497b5b69aff7a5aaee2585e", "4-089951792702f752c638c30effadaad2b65be417e4ca3d33c40e52302336f4b2240912", "1-d2a1091d13c9cc7a629fafd26202a657ad30d29df1bf6784dce150b495cdcdd722e9a4",
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

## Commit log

2019-01-20 Moved from local git repo to github
    [Securityfest_2019_badge_beta-B.Cu.gbr, Securityfest_2019_badge_beta-B.Mask.gbr, Securityfest_2019_badge_beta-B.Paste.gbr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]
2019-01-20 Removed unneeded stuff
    [Securityfest_2019_badge_beta-B.Cu.gbr, Securityfest_2019_badge_beta-B.Mask.gbr, Securityfest_2019_badge_beta-B.Paste.gbr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]
2019-02-03 Removed old kicad files
    [Securityfest_2019_badge_beta-B.Cu.gbr, Securityfest_2019_badge_beta-B.Mask.gbr, Securityfest_2019_badge_beta-B.Paste.gbr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]
2019-02-03 Added new kicad files
    [Securityfest_2019_badge_beta-B.Cu.gbr, Securityfest_2019_badge_beta-B.Mask.gbr, Securityfest_2019_badge_beta-B.Paste.gbr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]
2019-05-19 Removed more files
    [Test_cases.xlsx]
2019-05-19 Removed and added files
    [Securityfest_2019_badge.kicad_pcb, Securityfest_2019_badge.sch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]
2019-05-19 New bom
    [Securityfest_2019_badge_beta_BOM.xlsx]
